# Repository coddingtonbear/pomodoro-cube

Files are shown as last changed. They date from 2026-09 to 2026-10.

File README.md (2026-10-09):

https://github.com/user-attachments/assets/7382e785-1dbb-4c98-959f-1ba87e019f36

# pomodoro-cube

A desk cube that runs a pomodoro timer. Stand it on a face to pick the
interval, lay it face up to pause, lay it face down to switch it off. There are
no buttons — the only control is which way up it is.

The four timer faces

Forked from [fly-robin-fly/coffee_timer](https://github.com/fly-robin-fly/coffee_timer),
which does the same trick for coffee brew times.

The enclosure is on Printables as
[Pomodoro Cube](https://www.printables.com/model/1860676-pomodoro-cube); its
source is in [cad/](cad/README.md).

## Features

- **The faces are the interface** — each face of the cube means something
  different: a 25-minute work timer, a 5-minute break, flow mode's work and its
  break, pause, and off. Nothing to configure and nothing to press: the
  accelerometer reads which face is down, and that is the whole API.
- **Flow mode, for work that doesn't fit a fixed interval** — its work face
  counts *up* for as long as the cube stands on it, banking a fifth of what it
  counts as break time. The break face spends that bank. Fifty minutes of work
  buys ten of break, which is the fixed pair flow mode replaced; an hour and a
  half buys eighteen. Every 25 minutes it counts scores a pomodoro, which is
  what the arc's lap is showing. See [Flow mode](#flow-mode).
- **Home Assistant over BLE** — the cube broadcasts its state as a
  [BTHome v2](https://bthome.io/format/) advertisement, which Home Assistant
  discovers natively: no custom component, no MQTT, no ESPHome. See
  [Bluetooth](#bluetooth).

## How it works

Which way up the cube is sitting is the whole interface. There's an
accelerometer on the board, and the firmware turns what it reports into one of
six states: the four timer faces, face up, or face down.

Standing the cube on a timer face starts that face's timer — or, if you'd
paused one on that same face, picks it back up where you left off. The
countdown faces show an arc that drains as the time runs out, and its colour
says what comes next: a work timer shades from red through amber to green,
heading for the break, and a break shades from green to red, heading back to
work:

The arc draining over a five-minute timer

When a countdown reaches zero, the vibration motor buzzes and the whole face
flashes — green when it's time for a break, red when it's time to get back to
work — until you turn the cube to another face; if you don't, it gives up
and goes to sleep after thirty seconds:

A finished timer flashing

Work timers count towards a running pomodoro total (the one Home Assistant
sees), and breaks don't.

Laying the cube face up pauses whatever's running, and leaves the frozen
countdown on screen in muted colours:

Paused, and the low battery warning

The cube spends most of its life in deep sleep, and any movement wakes it back
up. The paused timer, the pomodoro count and the flow bank are all kept in
memory that survives deep sleep — but not a flat battery.

### Switching off

Face down is off. Every bump wakes a sleeping cube, so "off" has to mean
something a bit stronger than "asleep"; otherwise a cube in a bag would light
up and start a timer whenever it landed on an edge. Once it's face down, the
cube stays dark however much it's jostled, and whatever was running is parked
just as if you'd paused it.

To switch it back on, flip it three times: turn it face up, then over onto
its face and back up again, twice. The screen counts the flips down — a big
**2**, then **1**, "to go" — and answers the third with a buzz and **Let's
go**. Take more than five seconds over any one flip and it goes back to sleep,
still off; the next flip starts the count again from three.

## Flow mode

Sometimes 25 minutes just isn't the right length for a stretch of work. Flow
mode's work face counts _up_ instead of down, for however long you leave the
cube on it, and every five minutes you work banks a minute of break. The flow
break face then counts that bank back down: fifty minutes of work buys you a
ten-minute break, and an hour and a half buys eighteen.

The bank is a running balance rather than a one-time handoff, so several
stretches of work add up, and if you're interrupted partway through a break,
whatever's left stays banked for next time.

Both flow faces are drawn black on white so you can tell at a glance that
you're not on a fixed timer, and the work face shows what your bank would be
if you stopped right now:

Flow mode counting up with its bank, and the break it earned

The arc on the work face fills over 25 minutes and then starts over, counting a
pomodoro each time it comes back around. The first lap shades from red to green
like any work timer; every lap after that runs on from green to cyan, so the
arc snaps back to green each time a pomodoro is scored. The panel lights up for
a couple of seconds either side of that moment so you can see it happen.

## Bluetooth

The cube advertises its state as [BTHome v2](https://bthome.io/format/) —
service data under UUID `0xFCD2` — which Home Assistant discovers with no
custom component, no MQTT and no ESPHome. It is one-way and connectionless, so
it costs almost nothing next to the backlight.

Objects, in the ascending order the spec requires, totalling 30 of the 31 bytes
a legacy advertisement allows:

| Object | ID | Type | Meaning |
| --- | --- | --- | --- |
| Packet ID | `0x00` | uint8 | Increments on change, so receivers can dedupe |
| Voltage | `0x0C` | uint16, ×0.001 V | The smoothed pack voltage, uncorrected |
| Work | `0x0F` | binary | 1 for a work interval, 0 for a break |
| Connectivity | `0x19` | binary | 1 while awake, 0 in the advert sent before sleeping |
| Running | `0x27` | binary | Is the countdown advancing |
| Count | `0x3D` | uint16 | Pomodoros since the last power cycle: completed work timers, plus a flow lap each 25 minutes |
| Duration | `0x42` | uint24, ×0.001 s | Remaining, or elapsed while counting up |
| Duration 2 | `0x42` | uint24, ×0.001 s | What the timer started at, or 0 while counting up |

`Duration 2 == 0` means the timer is counting up, and `Duration` is then the
elapsed time.

Before it goes to sleep, the cube sends one last advertisement with `running`
off, so Home Assistant doesn't go on thinking a timer is running while the cube
is asleep.

### How it reaches the air

The work is split in two, because the halves fail in different ways and only one
of them can be tested without a radio:

- `bthome.cpp` assembles the payload, and is tested against exact bytes. It also
  holds `BTHome::Sequencer`, which decides when there is anything new to say:
  the firmware offers its state on every pass of the loop and the sequencer only
  produces an advertisement when the bytes a receiver would see have changed.
  That is what keeps the packet id meaning *"something changed"* rather than
  *"another second went by"* — and it is why a pack voltage wobbling below a
  millivolt doesn't churn it, since the comparison is on encoded bytes rather
  than the float behind them.
- `ble.cpp` hands the result to NimBLE. Non-connectable, no scan response, no
  GATT server and nothing to connect to: a BTHome device is a beacon. The radio
  goes on the air in two-second bursts at 100 ms, and is quiet in between.
  `BTHome::Scheduler` decides when a burst is due: at once when anything but the
  seconds remaining or the pack voltage has changed, and otherwise every 30
  seconds as a heartbeat, carrying wherever the countdown and the pack have got
  to. Home Assistant's countdown is therefore up to 30 seconds stale, and face
  changes, pauses, finishes and pomodoros arrive at once. The farewell goes out
  at the same 100 ms and stays on the air for the whole of the shutdown sequence — the panel
  being put away, the parting buzz, a second's pause — with the controller
  shut down last, immediately before the CPU stops, and never after less than a
  second on the air. That is a dozen-odd copies of the one advertisement that
  cannot be repeated later, where a fixed 400 ms used to send four, which a
  receiver scanning at a low duty cycle (an ESPHome Bluetooth proxy listens for
  30 ms in every 320 by default) could miss altogether.

The cube appears in Home Assistant under its BLE MAC — one above the WiFi MAC
printed on the board — because the payload already uses 30 of the 31 bytes a
legacy advertisement holds and there is nowhere left to put a name.

> [!NOTE]
> Home Assistant only offers a BTHome device its Bluetooth integration has
> actually *seen*, and the cube is silent while asleep. Stand it on a face before
> adding the integration, or there will be nothing to find.

The simulator prints the payload the firmware last published when you press `a`,
and `SIM_BLE_TRACE=1` prints every one as it goes out:

```
[sim] advertisement 3 (30 bytes): 02 01 06 1A 16 D2 FC 44 00 02 0C 3C 0F 0F 01 19 01 27 01 3D 00 00 42 90 DB 16 42 60 E3 16
[sim] farewell advertisement 4 (30 bytes): 02 01 06 1A 16 D2 FC 44 00 03 0C 3C 0F 0F 01 19 00 27 00 3D 00 00 42 90 DB 16 42 60 E3 16
```

## Hardware

### Parts

- **Board**: [Waveshare ESP32-S3-Touch-LCD-1.28](https://www.waveshare.com/wiki/ESP32-S3-Touch-LCD-1.28)
- **Battery**: a 102535 Li-Po cell ([the one used here](https://www.amazon.com/dp/B0GQB1DCTW))
- **Vibration motor**: [the one used here](https://www.amazon.com/dp/B0FQTHK9LH)
- **Screws**: 4× M2.6 × 6 mm self-tapping: two inside hold the display to the
  center, two outside hold the back on
- **Enclosure**: four printed parts; see [cad/](cad/README.md) or
  [Printables](https://www.printables.com/model/1860676-pomodoro-cube)

### The board

A [Waveshare ESP32-S3-Touch-LCD-1.28](https://www.waveshare.com/wiki/ESP32-S3-Touch-LCD-1.28),
which carries everything except the vibration motor: the 240×240 round GC9A01 over SPI,
a QMI8658 accelerometer over I²C, a LiPo connector with an ETA6096 charger and
the 200k/100k sense divider, and USB-C for flashing. Every pin in
`ArduinoIDE_V2/main/consts.h` matches that board — including the three that
distinguish it from the otherwise similar non-touch `ESP32-S3-LCD-1.28`
(backlight on GPIO2, LCD reset on GPIO14, IMU INT1 on GPIO4).

The one added component is a **vibration motor on GPIO15**, driven high to run
it. That is one of the six GPIOs the board brings out on its SH1.0 connector
(15, 16, 17, 18, 21 and 33), and the pin is held low through deep sleep. A GPIO
cannot supply a motor directly, so this wants a module with its own driver
transistor. There is no sounder: everything the cube has to say, it says by
buzzing.

| When | Pattern |
| --- | --- |
| Waking onto a timer face | Two short pulses |
| Set on a different face, resting faces included | One pulse |
| A timer running out | 400 ms on, 600 ms off, until the cube is turned to another face or sleeps |

A wake that finds the cube still resting goes back to sleep without a buzz,
because a buzz is movement and movement is what wakes it. For the same reason
the motor is stopped before the wake-on-motion detector is armed, taps are
ignored while it runs, and the alarm's silences are longer than the face
debounce, so the accelerometer always gets a quiet stretch in which to notice
the cube being turned. The patterns are in `consts.h`.

The board also has a **CST816S capacitive touch controller**, on the same I²C
bus as the accelerometer, which this firmware does not use at all. It's the
obvious place to start if the cube ever needs configuring on-device rather than
by reflashing.

## Building

Open `ArduinoIDE_V2/main` in the Arduino IDE. Dependencies, all from the
Library Manager:

- TFT_eSPI 2.5.43 (Bodmer)
- lvgl 8.3.11
- SensorLib 0.4.1 (Lewis He) — the library that provides `SensorQMI8658.hpp`.
  Searching the Library Manager for the header's name finds other people's
  QMI8658 libraries instead, none of which are this one
- NimBLE-Arduino 1.4.3 (h2zero) — **not** 2.x, which needs an ESP32 core of 3.x
  and up; this project is on 2.0.14. NimBLE rather than the core's bundled
  `BLEDevice.h` because that one is Bluedroid, which costs tens of kilobytes of
  RAM the cube would rather spend on LVGL

Two of them keep their configuration outside the sketch, and both have to be
linked into place before anything will work:

```bash
ln -s "$PWD/ArduinoIDE_V2/lv_conf.h"    ~/Arduino/libraries/lv_conf.h
ln -s "$PWD/ArduinoIDE_V2/User_Setup.h" ~/Arduino/libraries/TFT_eSPI/User_Setup.h
```

`lv_conf.h` sets only the five options that differ from LVGL's defaults, and
`sim/CMakeLists.txt` sets the same five, so the simulator and the board render
from identical settings. LVGL looks for it one directory *above* itself, which
is why it cannot live in the sketch folder.

`User_Setup.h` is the panel: GC9A01, 240×240, and the SPI pins. TFT_eSPI does
support a `tft_setup.h` in the sketch folder and this project used to rely on
it, but **that mechanism cannot work under the Arduino build**: TFT_eSPI.h
looks for `<tft_setup.h>` on the include path, and the sketch folder is not on
the path when the build compiles the library itself. The sketch's own files
find it and the library's do not, so the library compiles against its default
— an ILI9341 on entirely different pins — and the panel stays black with
nothing anywhere to say why. Overriding `User_Setup.h` configures every
translation unit alike. `display.cpp` now refuses to compile if `GC9A01_DRIVER`
is undefined, so a missing symlink is a build error rather than a dead screen.

Board settings, matching the ESP32-S3-WROOM-1 the Waveshare board carries:
**ESP32S3 Dev Module**, flash size **16MB**, PSRAM **disabled** (this module
has none). USB CDC on boot stays **disabled** — the USB-C port is a CH343
UART bridge rather than the S3's native USB, so `Serial` is UART0 either way
and the port appears as `/dev/ttyACM0`. The default 4MB partition scheme is
kept despite the 16MB flash: the sketch is about 880 kB against that scheme's 1.3 MB
app slot, and nothing here uses the filesystem.

The IDE isn't needed to flash it, though — `tools/flash.sh` compiles and
uploads in one go with the `arduino-cli` the IDE ships with, passing those board
settings itself. It also builds at `-O2` rather than the core's `-Os`, which
draws the face about 14% faster; the IDE has no setting for that, so an IDE
build works the same and just draws a little slower:

```bash
tools/flash.sh              # compile, upload, reset
tools/flash.sh --build-only # just check it compiles
tools/flash.sh --monitor    # ...and then tail UART0 at 115200
```

It checks the two symlinks above before compiling, loads `cdc_acm` if
`/dev/ttyACM0` is missing (the module is blacklisted on some machines, so the
port doesn't appear on its own), and resets the board a second time after
uploading — straight out of an upload the QMI8658 has come up silent, with
every read returning zero, and a second reset clears it.

`ArduinoIDE_V2/main/src/` began life as SquareLine Studio output and is now
maintained by hand. **Re-exporting from `SquareLine/coffee_timer.spj` would
overwrite it**, countdown font included.

## Developing without the hardware

```bash
./sim/run.sh
```

This compiles the real firmware for a Linux desktop and draws LVGL into an SDL
window instead of a GC9A01 over SPI. It isn't a reimplementation: `main.ino`,
`display.cpp`, `util.cpp`, `indicators.cpp`, `rtc_state.cpp`, `tilt.cpp`,
`bthome.cpp`, `battery.cpp`, `haptic.cpp` and `haptic_pattern.cpp` all compile
exactly as they ship, against fake `Arduino.h`, `TFT_eSPI`, `Wire` and
`driver/rtc_io` headers. Only `qmi.cpp` and `ble.cpp` are replaced, because they
need the vendor IMU driver and NimBLE.

RTC memory is modelled rather than faked — the block survives a simulated deep
sleep, and a cold boot fills it with junk rather than zeroes, so the magic-word
guard is genuinely exercised.

See [sim/README.md](sim/README.md) for the controls, the scripted-screenshot
environment variables, and what the simulator can't tell you.

Host tests cover the parts that are pure logic — the face-to-timer mapping, the
flow bank's arithmetic, the arc's fill and colour ramp, the lap indicator
and what scores off it, the switch from 25:00 to 1h25 past an hour, the low-battery threshold,
the angle the face is drawn at, the RTC guard, the vibration patterns, the
order the sleep path shuts things down in, and the BTHome encoder's exact output
bytes:

```bash
cmake --build sim/build && ctest --test-dir sim/build --output-on-failure
```

## Changing the countdown font

```bash
tools/convert-font.sh fonts/Oswald-SemiBold.ttf 62
```

The font slot is named for its role rather than the typeface, so nothing else
needs editing. The script subsets to the digits and colon, renders at 4 bpp for
antialiasing, and equalises the digit widths so the countdown doesn't shift
sideways as it ticks — most faces draw a much narrower `1` than `0`, and on a
centred label that slides the whole time every second.

The current face is [Oswald](https://github.com/google/fonts/tree/main/ofl/oswald)
SemiBold at 62px, chosen because it's condensed: on a 240px round panel with an
arc eating the edges, height is the scarce resource. See
[fonts/README.md](fonts/README.md) for why the weight is pinned to a static
instance.

## Layout

```
ArduinoIDE_V2/lv_conf.h   LVGL settings, linked into ~/Arduino/libraries
ArduinoIDE_V2/User_Setup.h TFT_eSPI panel settings, linked into the library
ArduinoIDE_V2/main/       the firmware, built with the Arduino IDE
ArduinoIDE_V2/main/src/   the LVGL UI, originally SquareLine Studio output
SquareLine/               the SquareLine Studio project the UI came from
cad/                      the enclosure, exported from Fusion 360; see cad/README.md
fonts/                    source faces for the countdown label
sim/                      desktop simulator and host tests
tools/                    flashing the board, and font conversion
```

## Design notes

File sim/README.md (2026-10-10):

# Desktop simulator

Runs the cube's firmware on a Linux desktop, with LVGL drawing into an SDL
window instead of into the GC9A01 over SPI. The point is to be able to work on
the UI and the timer behaviour without the hardware.

The firmware is **not** forked for this. `main.ino`, `display.cpp`, `util.cpp`,
`battery.cpp` and `haptic.cpp` are compiled exactly as they ship, against the
shims in `shim/`. The one exception is `qmi.cpp`, which needs the vendor
QMI8658 driver; `src/sim_qmi.cpp` stands in for it and synthesises an
accelerometer reading for whichever face the sim says the cube is resting on.

## Running

```bash
./run.sh
```

First run fetches LVGL v8.3.11 (matching what SquareLine Studio generated
against) and configures CMake; later runs just rebuild. Needs `cmake`, a C++17
compiler and `libsdl2-dev`:

```bash
sudo apt install cmake build-essential libsdl2-dev
```

## Controls

| Key | Effect |
| --- | --- |
| `1` `2` `3` `4` | Rest the cube on a face — 0°, 90°, 180°, 270° |
| | `3` is flow's work face, which counts up, and `4` spends the break it banks |
| `z` `x` | Lean it 5° anticlockwise / clockwise off that face, up to 40° |
| `0` or `s` | Lay it face down |
| `u` | Lay it face up. On a switched-off cube, `u` `0` `u` `0` `u` is the three flips that switch it on |
| `b` | Cycle the low-battery warning: forced on, forced off, voltage-driven |
| `[` `]` | Lower / raise the simulated pack voltage |
| `t` | Tap the cube, which brightens the panel for ten seconds |
| `d` | Double-tap it |
| `v` | Toggle between the viewer's view and the raw panel |
| `m` | Toggle the round-panel mask |
| `a` | Print the BLE advertisement the firmware last published |
| `r` | Reboot, as a wake-from-deep-sleep would |
| `q` or `Esc` | Quit |

`b` exists because nudging the voltage is a slow way to see the warning: the
firmware averages ten readings taken five seconds apart, so a change takes most
of a minute to land. The forced states still go through the firmware's own
threshold, just with the voltage model skipped. `[` or `]` hands control back.

By default the window shows the panel as someone looking at the cube sees it:
turned to the angle the cube is held at, which is the face it is on plus any
lean. A face that has caught up with the cube is therefore upright, and one
that has not is as crooked as it would be in the hand — which is the only way
to see a turn being eased. `v` switches to the physical panel, where the
content appears rotated — useful when checking what `tft.setRotation()` is
actually doing.

The simulated cube changes face in no time at all, which no hand does, so a
turn here is the worst case the easing has to cope with rather than what one
looks like.

Face down switches off and blanks the panel; face up pauses, leaving the frozen
countdown lit. Either way any key re-executes the process, reproducing the cold
boot the IMU interrupt causes on hardware. A face key wakes onto that face and
any other key onto 90°. To switch a face-down cube back on, wake it with `u`
and press `k` or `d` within five seconds.

## Scripted screenshots

Environment variables let a script capture the panel without a display:

```bash
SDL_VIDEODRIVER=dummy SIM_ORIENTATION=180 \
  SIM_SCREENSHOT=/tmp/face.bmp SIM_SCREENSHOT_MS=1500 ./build/sim
```

| Variable | Effect |
| --- | --- |
| `SIM_ORIENTATION` | Boot on a face: `0`, `90`, `180`, `270`, `up` or `down` |
| `SIM_BATTERY` | Starting pack voltage in volts, e.g. `3.35` |
| `SIM_SCREENSHOT` | Where to write the frame |
| `SIM_SCREENSHOT_MS` | When to grab it, in ms since boot |
| `SIM_KEYS` | Keys to press, e.g. `b`, `mv`, or `u@12000` for 12s in |
| `SIM_BLE_TRACE` | Print every BLE advertisement as it goes out |
| `SIM_TIME_SCALE` | Run the firmware's clock this many times faster than real time, e.g. `600` |

`SIM_KEYS` entries are comma-separated, and `key@ms` presses one part-way
through a run — which is how pausing gets exercised, since it needs a face
change while a countdown is already going.

`SIM_BLE_TRACE` with `SIM_KEYS` is how the advertising sequence gets checked
without a keyboard — including the farewell, which only goes out on the way into
deep sleep:

```bash
SDL_VIDEODRIVER=dummy SIM_BLE_TRACE=1 SIM_ORIENTATION=0 SIM_KEYS=u@6000 ./build/sim
```

`SIM_SCREENSHOT_MS` also takes a comma-separated list, which captures a
countdown at several points in one run; each file then gets its elapsed time
appended to the name. The sim exits after the last capture.

```bash
SDL_VIDEODRIVER=dummy SIM_ORIENTATION=90 SIM_SCREENSHOT=/tmp/arc.bmp \
  SIM_SCREENSHOT_MS=1000,76000,151000,226000 ./build/sim
```

`SIM_TIME_SCALE` speeds up `millis()`, `delay()`, and with them the times in
`SIM_KEYS` and `SIM_SCREENSHOT_MS`, which are all in simulated milliseconds.
A flow stint past its first hour is a minute away at `100`:

```bash
SDL_VIDEODRIVER=dummy SIM_TIME_SCALE=100 SIM_ORIENTATION=180 \
  SIM_KEYS=t@5995000 SIM_SCREENSHOT=/tmp/hour.bmp SIM_SCREENSHOT_MS=6000000 ./build/sim
```

The timer on screen falls behind the clock, though. The firmware advances it
by at most one second per pass of `loop()`, and a pass still takes as long on
the wall clock as its drawing does — a few milliseconds, which at `100` is
most of a simulated second. The run above shows about 1:18, not 1:40, and at
`600` a pass is several seconds and an hour's run shows about fifteen minutes.
Aim a screenshot by what is on screen rather than by the arithmetic, and keep a
tap no more than a few simulated seconds before the capture it is meant to
brighten.

## Tests

`tests/` holds host tests for the firmware's pure logic — the face-to-timer
mapping and the flow bank's arithmetic in `util.cpp`, the
accelerometer vectors the faces correspond to, and the arc fill, arc colour,
flow lap indicator, switch from 25:00 to 1h25 and low-battery threshold in
`indicators.cpp`. They build as part of the same project:

```bash
cmake --build build && ctest --test-dir build --output-on-failure
```

## What is and isn't simulated

Faithful: the LVGL render path and the SquareLine UI, panel rotation, the
countdown and its debounce, the arc and battery indicator, the deep-sleep
transitions, and RTC memory — the block survives a simulated deep sleep and is
filled with junk on a cold boot, exactly as the real thing would be, so the
magic-word guard is genuinely exercised rather than getting away with a benign
block of zeroes. A paused panel stays lit because the sim decides from the
panel's own state (backlight on, no Sleep In command) rather than from knowing
the firmware is asleep.

One gap around pausing: the device holds `TFT_BL_PIN` through deep sleep, so the
frame stays lit across the wake until `Display::setup()` releases the hold. The
sim's wake is a fresh process, so its panel goes dark for the moment the boot
takes. Nothing depends on it, but the real cube will look slightly smoother.

There is no radio: `a` prints the BTHome payload `bthome.cpp` builds rather than
transmitting it, which is enough to read a payload back against the spec or paste
it into a decoder.

Stubbed: the vibration motor is a flag that follows its pin and shows up in the
window title as `BUZZ`, so the pattern timing is visible. It does not shake the
simulated accelerometer, so how the motor disturbs the IMU is a question for the
board. I2C,
RTC GPIO holds and the CPU frequency change are no-ops. Timing comes from the
host clock, so this says nothing about how the real ESP32 performs at 80 MHz.

## Layout

```
shim/     Arduino.h, TFT_eSPI, Wire, driver/rtc_io -- the hardware APIs faked
src/      the simulated panel, input state, IMU stand-in and SDL entry point
tests/    host tests for the firmware's pure logic, plus link stubs
```

`shim/` is deliberately minimal: only the calls this firmware actually makes are
provided, so reaching for a new hardware API shows up as a compile error rather
than silently doing nothing.

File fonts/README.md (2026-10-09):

# Fonts

Source faces for the countdown label and the switch-on prompt, kept here so
the conversion is reproducible. `tools/convert-font.sh` reads from here and
writes `ArduinoIDE_V2/main/src/ui_font_Countdown_54.c` (or wherever `OUT`
says).

## Oswald-SemiBold.ttf

The countdown face. Oswald is a variable font upstream; this is the wght=600
instance, pinned with:

```
fonttools varLib.instancer Oswald[wght].ttf wght=600 -o Oswald-SemiBold.ttf
```

The instance matters — `lv_font_conv` takes a variable font's default instance,
which for Oswald is Regular, and Regular is too light for the panel.

Regenerate the countdown font with:

```
RANGE=0x30-0x3A,0x68 tools/convert-font.sh fonts/Oswald-SemiBold.ttf 62
```

The range adds `h` to the digits and colon, for the hours past an hour (1h25).

62px rather than the script's default 54: Oswald is condensed, so it can run
taller before the digits reach the arc.

The switch-on prompt's count is the same face, much larger, and only the two
digits it ever shows:

```
OUT=$PWD/ArduinoIDE_V2/main/src/ui_font_FlipCount.c RANGE=0x31-0x32 TABULAR=0 \
  tools/convert-font.sh fonts/Oswald-SemiBold.ttf 150
```

Licensed under the SIL Open Font License 1.1, in `OFL.txt`.
Upstream: https://github.com/google/fonts/tree/main/ofl/oswald

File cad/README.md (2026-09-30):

# Enclosure

A 44.9 mm cube, designed in Fusion 360. The design is the Fusion document
**Pomodoro Box**; the files here are exports of it, and are replaced wholesale
whenever it changes rather than edited.

It's published on Printables as
[Pomodoro Cube](https://www.printables.com/model/1860676-pomodoro-cube).

| file | what it is |
|---|---|
| [`pomodoro-cube.f3d`](pomodoro-cube.f3d) | the Fusion 360 design itself, for opening and remixing |
| [`pomodoro-cube.step`](pomodoro-cube.step) | the assembly: one component per part, in their assembled positions, without the board |
| [`pomodoro-cube.3mf`](pomodoro-cube.3mf) | all four parts laid out on one plate, ready to slice |
| [`step/`](step/) | one STEP per part, oriented for printing like the STLs |
| [`stl/`](stl/) | one STL per printed part, already oriented for printing |

To print, open the 3MF, or the per-part STEPs or STLs. The assembly STEP is for
CAD; a slicer would load its parts nested inside each other.

## The parts

| part | size (mm) | print | files |
|---|---|---|---|
| center | 44.9 × 44.9 × 38.9 | upright, as designed | [STL](stl/pomodoro-cube-center.stl), [STEP](step/pomodoro-cube-center.step) |
| face | 44.9 × 44.9 × 11.4 | outer face down | [STL](stl/pomodoro-cube-face.stl), [STEP](step/pomodoro-cube-face.step) |
| back | 44.9 × 44.9 × 3.0 | outer face down | [STL](stl/pomodoro-cube-back.stl), [STEP](step/pomodoro-cube-back.step) |
| barrier | 38.5 × 38.5 × 1.0 | flat | [STL](stl/pomodoro-cube-barrier.stl), [STEP](step/pomodoro-cube-barrier.step) |

**Center** is the shell, with the display pocket, the internal ledges and the
openings in its side walls. **Face** is the display's front and
plugs into the top of it; **back** closes the bottom. **Barrier** is a thin
plate that sits inside the shell about 10 mm behind the display.

Besides the board, it holds a 102535 Li-Po battery and a vibration motor, and
four M2.6 × 6 mm self-tapping screws hold it together: two inside fix the
display to center, and two outside fix back to center. See
[Parts](../README.md#parts) for links.

Each STL was checked watertight on export, and each part lies in whichever
axis-aligned orientation leaves the least overhang steeper than 45°. Face still
has some, from the display bevel and the edge rounds on the bed.

## Updating

Fusion runs on another machine, so exports are made there and copied in. When
the design changes, replace every file here, keeping the names so links to them
survive:

- **Fusion archive**: the design as-is.
- **STL**: every body, in its print orientation.
- **STEP**: the design keeps all four parts as bodies of one component, so
  exporting the root gives a single part that slicers load as one lump. Instead,
  copy the bodies into a scratch design with one component each: one set in
  place, exported together as the assembly, and one set rotated to print
  orientation (face and back turn 180° about X), each exported alone.
- **3MF**: all four parts, in print orientation, as separate objects on one
  plate. The current one was built from the STLs, in a 2 × 2 grid with 10 mm
  gaps centred at (100, 100) so it fits a 180 mm bed.

## History

Until September 2026 the enclosure was a parametric build123d model here: a
55 mm cube in a band, two plates and two clamp bars, with every dimension
derived from the board's published STEP. It was taken into Fusion and then
redesigned there over many iterations, and was removed once it no longer
described the part that is printed. It is in the git history before this
directory was replaced.

The shell descends from Robin's
[Timer cube](https://www.printables.com/model/1774785-timer-cube), the
enclosure for [fly-robin-fly/coffee_timer](https://github.com/fly-robin-fly/coffee_timer),
which the firmware here is forked from.

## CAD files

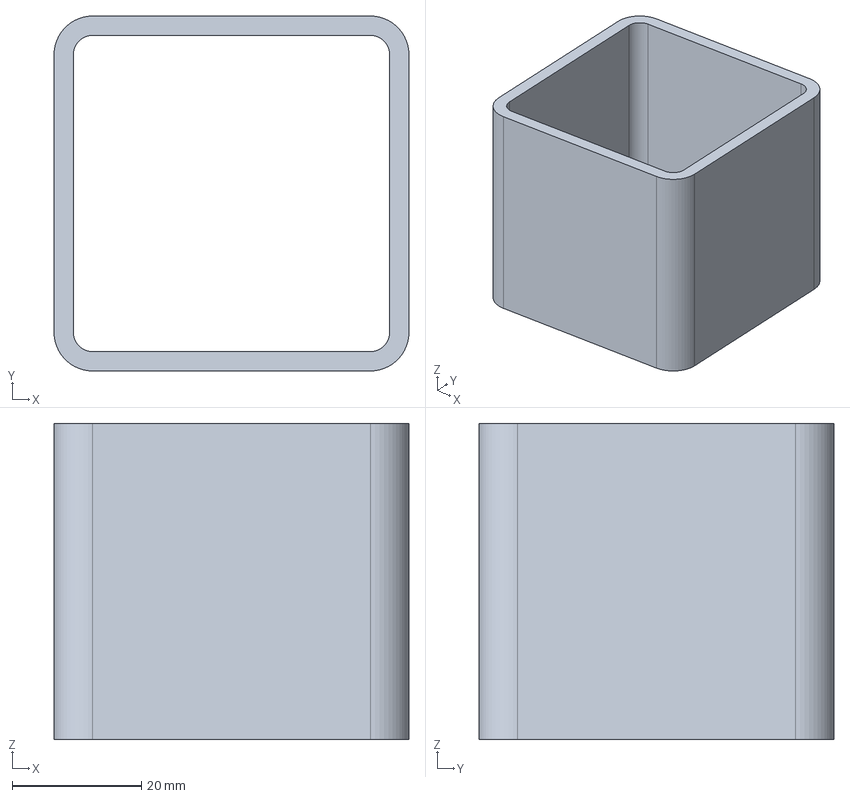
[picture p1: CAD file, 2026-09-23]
cad/build/band-plates-as-faces.step
55.0 x 55.0 x 49.0 mm

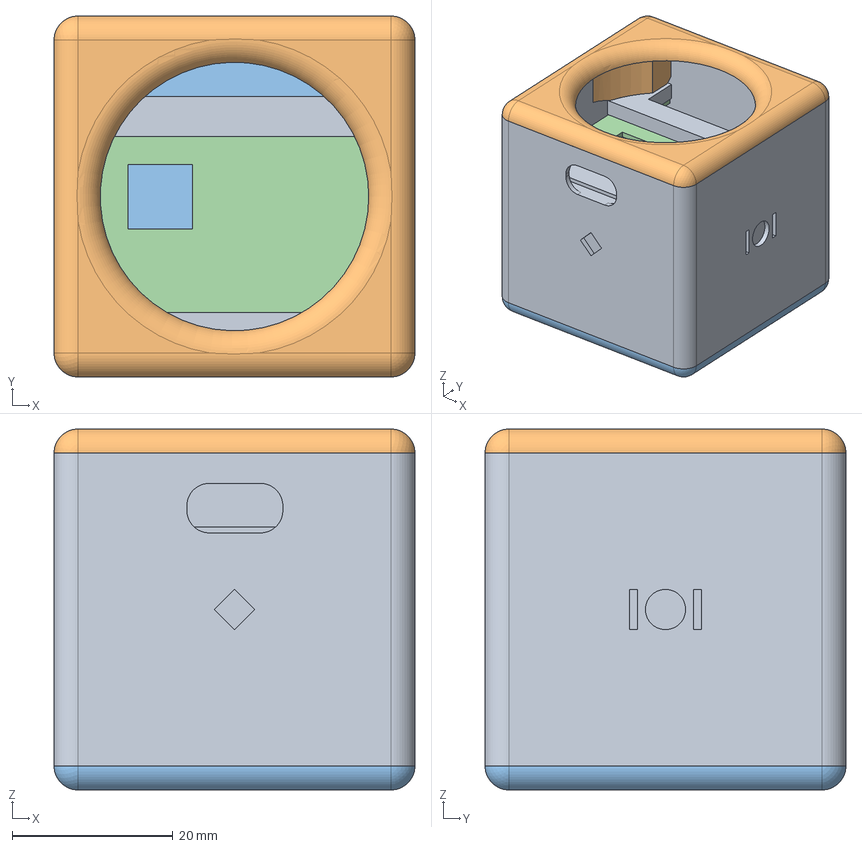
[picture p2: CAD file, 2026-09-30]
cad/pomodoro-cube.step
44.9 x 44.9 x 44.9 mm
Center
Back
Barrier

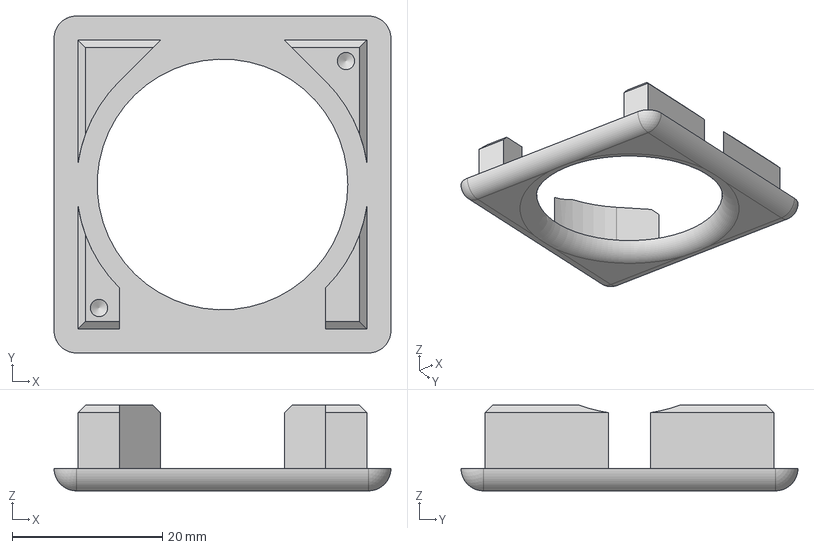
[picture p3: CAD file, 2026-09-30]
cad/step/pomodoro-cube-face.step
44.9 x 44.9 x 11.4 mm

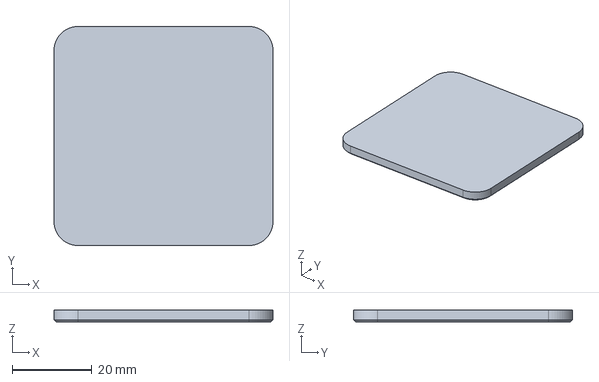
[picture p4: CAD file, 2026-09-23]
cad/build/back-plate-plates-as-faces.step
55.0 x 55.0 x 3.00 mm

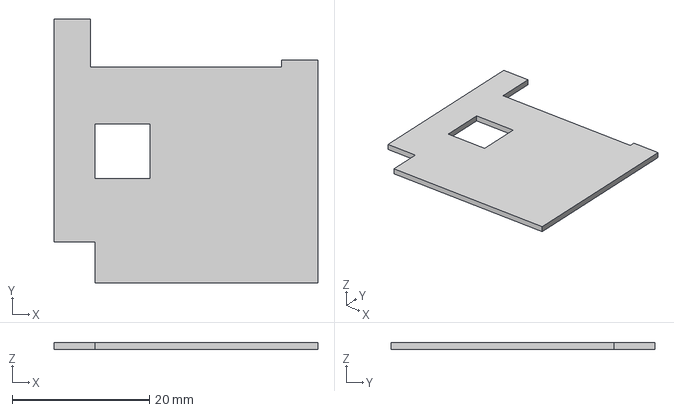
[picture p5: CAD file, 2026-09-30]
cad/step/pomodoro-cube-barrier.step
38.5 x 38.5 x 1.00 mm

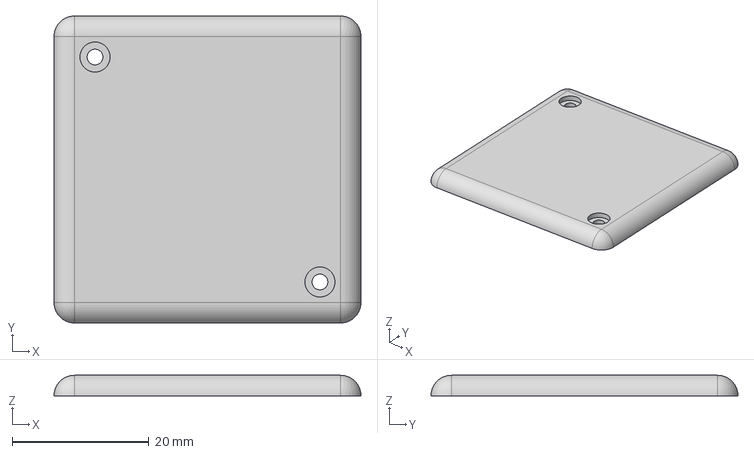
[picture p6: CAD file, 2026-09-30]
cad/step/pomodoro-cube-back.step
44.9 x 44.9 x 3.00 mm

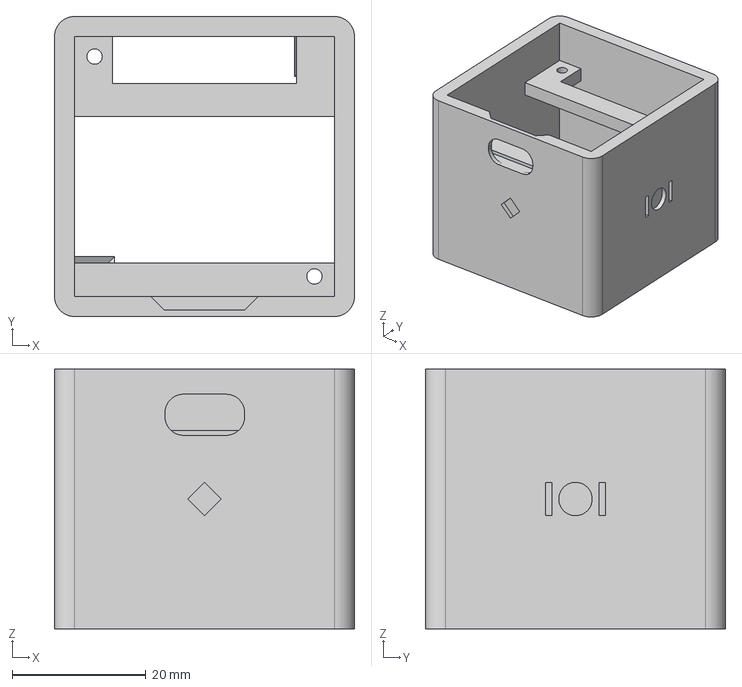
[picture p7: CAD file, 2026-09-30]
cad/step/pomodoro-cube-center.step
44.9 x 44.9 x 38.9 mm

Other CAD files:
cad/pomodoro-cube.3mf
cad/pomodoro-cube.f3d
cad/stl/pomodoro-cube-back.stl
cad/stl/pomodoro-cube-barrier.stl
cad/stl/pomodoro-cube-center.stl
cad/stl/pomodoro-cube-face.stl

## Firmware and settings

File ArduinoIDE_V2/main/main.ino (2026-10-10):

#include <Arduino.h>
#include "consts.h"
#include "battery.h"
#include "display.h"
#include "util.h"
#include "display.h"
#include "qmi.h"
#include <lvgl.h>
#include "haptic.h"
#include "rtc_state.h"
#include "ble.h"
#include "tilt.h"
#include "nap.h"


// Counting down, this is the time left. Counting up, it is the time elapsed.
int remSeconds = 0;
// The interval being counted down, and 0 while counting up: nothing was chosen.
int selSeconds = 0;
TimerKind timerKind = TimerKind::Work;
TimerMode timerMode = TimerMode::Countdown;
// True when the countdown on screen is the flow bank draining, so each tick has
// to write the new balance back. The fixed faces leave the bank alone.
bool spendingFlowBank = false;
// One of flow's faces, either of them: the panel inverts for both.
bool onFlowFace = false;
unsigned long lastTick = 0;  // last count tick timestamp
// When the timer on screen ran out, which is what the sleep that ends an
// unanswered alarm is timed from.
unsigned long startedAlarm = 0;
// The timer face the cube was last stood on, so a pause knows what it paused.
Orientation lastTimerFace = Orientation::UNDEFINED;
// When the cube was last set on a different face. Only the backlight reads it:
// a face change is a decision worth lighting the panel for.
unsigned long lastFaceChange = 0;
// When the cube was last tapped, or 0 for not since this boot. Only the
// backlight reads this one too.
unsigned long lastTap = 0;
// When a reading last showed the cube being moved, which keeps the loop fast
// for a moment after it stops.
unsigned long lastMoved = 0;
// Lying face up with a timer parked, and awake: nothing counts, the panel
// shows the parked figures, and the loop goes on watching the faces so that
// standing the cube back up is a face change like any other rather than a
// wake. `pausedAt` is what the sleep that ends a forgotten pause is timed from.
bool paused = false;
unsigned long pausedAt = 0;

// The angle the face is drawn at, followed from the accelerometer on every
// pass. Nothing to do with which face the cube is on, which is debounced and
// chooses the timer; this only turns the picture.
Tilt::Tracker tilt;

// Feed the tracker whatever the accelerometer had to say, including nothing.
// True when the angle to draw has moved.
bool senseTilt(bool haveReading, float ax, float ay, float az) {
  return tilt.update(haveReading && Util::isGravityOnly(ax, ay, az), ax, ay, millis());
}

// How long since the last tap, or past any window when there has not been one.
// millis() - 0 is millis(), which reads as a tap a moment ago for the first ten
// seconds of every boot.
unsigned long sinceTap() {
  return lastTap == 0 ? ~0UL : millis() - lastTap;
}


// A flow stint has ended: a fifth of it is credited to the break bank, on top of
// whatever was already there. Any stint that counted a second at all credits
// something -- a cube turned through the flow face on its way elsewhere never
// reaches a second, so there is nothing to screen out.
//
// Nothing is counted here. A stint scores by the lap while it runs, not by the
// stint when it stops, so its last partial lap is worth no more than abandoning
// a 25-minute timer at 24:00 is.
void bankFlowStint(int elapsed) {
  RtcState::addFlowBank(RtcState::data(), Util::flowBreakCredit(elapsed));
}

bool countingUp() {
  return timerMode == TimerMode::CountUp;
}

// What the panel is drawn from. The bank shown on a running stint includes what
// that stint has earned so far, because what you want to know while looking at
// it is what turning the cube over would give you.
Display::TimerView timerView() {
  const int banked = RtcState::flowBank(RtcState::data());
  return {remSeconds, selSeconds, countingUp(), onFlowFace, timerKind == TimerKind::Work,
          countingUp() ? Util::flowBankPreview(banked, remSeconds) : banked};
}

// What goes out over BLE. The packet id is left at zero: BLE::publish() hands
// this to a BTHome::Sequencer, which numbers it and drops it if nothing has
// changed, so this is free to be called on every pass.
BTHome::State bthomeState() {
  BTHome::State state;
  state.packetId = 0;
  state.batteryVolts = Util::batteryVolts();
  state.awake = true;
  // A stint counting up is running from its first second, before remSeconds has
  // anything in it.
  state.running = !paused && (countingUp() || remSeconds > 0);
  state.work = timerKind == TimerKind::Work;
  state.pomodoroCount = RtcState::data().pomodoroCount;
  state.remainingSeconds = remSeconds;
  state.selectedSeconds = selSeconds;
  return state;
}


// Everything standing the cube on a timer face asks for: closing off whatever
// the face being left was counting, picking up a pause that belongs to the new
// one, and repainting to match. Called from loop() when the debounce settles,
// and from setup() for the face a wake settles onto -- that one has already
// been through the debouncer, so nothing in loop() would announce it.
void applyFace(Orientation ori) {
  // Turning off the flow face ends the stint it was counting. Not out of a
  // pause, where the stint is the parked one and is banked as that below.
  if (!paused && countingUp() && ori != lastTimerFace) bankFlowStint(remSeconds);
  paused = false;

  // So does standing the cube on a face that abandons a parked one. The
  // pause itself is consumed by takePause() below either way; this is only
  // about banking what it was worth.
  {
    const RtcState::Data &stored = RtcState::data();
    if (RtcState::hasPause(stored) && stored.pausedCountingUp &&
        stored.pausedFace != ori) {
      bankFlowStint((int)stored.pausedRemaining);
    }
  }

  lastTimerFace = ori;

  // Read rather than spend: the bank is a balance, and only the break face
  // draining it writes it down. Every other face leaves it where it is, so
  // a spell on the 25-minute face doesn't cost you the break you earned.
  const Util::TimerSpec spec = Util::getTimerSpec(ori, RtcState::flowBank(RtcState::data()));
  spendingFlowBank = spec.spendsBank;
  onFlowFace = spec.flow;

  bool resumesCountingUp = false;
  if (RtcState::takePause(RtcState::data(), ori, remSeconds, selSeconds,
                          resumesCountingUp)) {
    timerMode = resumesCountingUp ? TimerMode::CountUp : TimerMode::Countdown;
    timerKind = spec.kind;
  } else {
    timerKind = spec.kind;
    timerMode = spec.mode;
    remSeconds = spec.mode == TimerMode::CountUp ? 0 : spec.seconds;
    selSeconds = spec.mode == TimerMode::CountUp ? 0 : spec.seconds;
  }
  // A break face turned to with an empty bank has no time to count, so it
  // is finished before it starts. Dating the alarm from here rather than
  // leaving the last finish's timestamp in place is what gives it the usual
  // thirty seconds before sleeping, instead of a stale one that could sleep
  // the cube on the spot.
  if (!countingUp() && remSeconds == 0) startedAlarm = millis();

  // At the angle the cube is actually held, which by now the tracker has been
  // following for at least the length of the debounce. The face's own angle is
  // only the fallback for a tracker that has somehow heard nothing.
  if (!tilt.hasAngle()) tilt.seed(Tilt::faceAngle(ori));
  Display::setAngle(tilt.angle());
  Display::updateTimer(timerView());
  lastTick = millis();
}

// Poll the accelerometer until one reading has held still long enough to be
// believed, or until the cube has plainly been in a hand for too long to wait
// out. UNDEFINED means it never settled, which is not a resting face and so
// boots the cube -- the right way round to be wrong.
Orientation settleOrientation() {
  const unsigned long deadline = millis() + WAKE_SETTLE_TIMEOUT_MS;
  while (millis() < deadline) {
    float ax, ay, az;
    const bool haveReading = QMI::getAccelerometer(ax, ay, az);
    // Followed from here, with no panel up yet to draw on, so that the first
    // frame is drawn at the angle the cube is held at rather than swinging
    // round to it.
    senseTilt(haveReading, ax, ay, az);
    if (haveReading && Util::updateOriDebounce(ax, ay, az, millis())) {
      return Util::getDebouncedOriState();
    }
    delay(20);
  }
  return Orientation::UNDEFINED;
}

// The frame a parked cube shows: the figures as they stood when it was set
// down, drawn from the stored pause rather than from the live timer, which on
// this path has not been set up and holds nothing.
Display::TimerView pausedView(const RtcState::Data &stored) {
  const int banked = RtcState::flowBank(stored);
  // The face it was paused from is what says whether this is one of flow's,
  // which the break face is as much as the work face -- countingUp alone would
  // draw a paused flow break in the fixed faces' colours.
  const Util::TimerSpec spec = Util::getTimerSpec(stored.pausedFace, banked);
  const bool up = stored.pausedCountingUp;
  return {(int)stored.pausedRemaining, (int)stored.pausedSelected, up, spec.flow,
          spec.kind == TimerKind::Work, up ? Util::flowBankPreview(banked, (int)stored.pausedRemaining) : banked};
}

// Hold the parked timer on the panel with the cube awake. The pause itself is
// already in RTC memory, which is where standing the cube back up will take it
// from; the live timer is set to match so that what is advertised, and what is
// parked again if the cube is turned face down from here, are the same figures.
void holdPause() {
  const RtcState::Data &stored = RtcState::data();
  const Util::TimerSpec spec =
      Util::getTimerSpec(stored.pausedFace, RtcState::flowBank(stored));
  lastTimerFace = stored.pausedFace;
  remSeconds = (int)stored.pausedRemaining;
  selSeconds = (int)stored.pausedSelected;
  timerMode = stored.pausedCountingUp ? TimerMode::CountUp : TimerMode::Countdown;
  timerKind = spec.kind;
  spendingFlowBank = spec.spendsBank;
  onFlowFace = spec.flow;

  paused = true;
  pausedAt = millis();

  // Square on the face the timer was running on, which is how a wake that has
  // to redraw this frame will draw it. A cube laid down part-way through a
  // turn would otherwise be parked at whatever angle the turn had reached.
  Display::rotateScreen(stored.pausedFace);
  Display::updateTimer(pausedView(stored));
  Display::showPaused();
}

// Follow the faces for up to `forMs`, and return the first face other than
// `current` the cube settles on, or `current` if it settles on nothing else.
Orientation watchFaces(unsigned long forMs, Orientation current) {
  const unsigned long started = millis();
  while (millis() - started < forMs) {
    feedLoopWDT();
    float ax, ay, az;
    if (QMI::getAccelerometer(ax, ay, az) && Util::updateOriDebounce(ax, ay, az, millis())) {
      const Orientation face = Util::getDebouncedOriState();
      if (face != current) return face;
    }
    delay(20);
  }
  return current;
}

// A switched-off cube has been woken: listen for the gesture that switches it
// back on. Dark and silent until the first flip -- no panel, no radio, no buzz
// -- because most wakes of a switched-off cube are a bag being carried, and the
// only thing worth spending on one of those is getting back to sleep.
bool heardSwitchOn() {
  Util::SwitchOnListener listener(millis());
  for (;;) {
    feedLoopWDT();
    float ax, ay, az;
    const bool haveReading = QMI::getAccelerometer(ax, ay, az);
    const Util::SwitchOnVerdict verdict = listener.update(haveReading, ax, ay, az, millis());
    if (verdict != Util::SwitchOnVerdict::Listening) {
      Serial.printf("[trace] SWITCH_ON verdict=%d flipsToGo=%d\n", (int)verdict,
                    listener.flipsToGo());
      return verdict == Util::SwitchOnVerdict::On;
    }
    // Lit from the first flip, which lands face up and so is the first moment
    // there is anyone to read it. A wake in a bag never gets this far, and
    // stays dark. The panel then stays up until the cube sleeps or is switched
    // on, face down between flips included.
    if (listener.flipsToGo() < SWITCH_ON_FLIPS) Display::showFlipsToGo(listener.flipsToGo());

    delay(20);
  }
}
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
void loop() {
  // Passes are paced to start LOOP_PASS_MS apart, the wait filling whatever
  // the last pass left of that rather than being added to it. A fixed delay
  // was free while a pass was nothing but the delay, and once drawing a
  // leaning face took 37 ms it made every frame 20 ms later than it had to be.
  // Never less than a millisecond, so a run of long passes still hands the
  // core back to the scheduler between them.
  //
  // How far apart is decided at the end of the pass before, by Util::loopPassMs:
  // fast while anything needs it, slower while the cube just sits dimmed.
  //
  // An idle wait is light-slept rather than spun through, unless the radio is
  // on the air: see Nap and BLE::onAir().
  static uint32_t passStart = 0;
  static uint32_t passMs = LOOP_PASS_MS;
  static bool idle = false;
  const uint32_t spent = millis() - passStart;
  const uint32_t wait = spent < passMs ? passMs - spent : 1;
  // What a soak run reads: how much of each minute went to naps, and whether
  // the heap is holding steady through the radio's bring-ups and teardowns.
  static unsigned long lastSoak = 0;
  static uint32_t napMs = 0, naps = 0;
  if (millis() - lastSoak >= 60000UL) {
    Serial.printf("[trace] SOAK t=%lu naps=%u napMs=%u heap=%u largest=%u\n", millis(),
                  (unsigned)naps, (unsigned)napMs, (unsigned)ESP.getFreeHeap(),
                  (unsigned)ESP.getMaxAllocHeap());
    lastSoak = millis();
    naps = napMs = 0;
  }
  if (idle && wait >= NAP_MIN_MS && !BLE::onAir()) {
    Display::finishDrawing();
    Nap::sleepFor(wait);
    naps++;
    napMs += wait;
  } else {
    delay(wait);
  }
  passStart = millis();

  Display::render();

  float ax, ay, az;
  const bool haveReading = QMI::getAccelerometer(ax, ay, az);
  // Followed throughout, drawn only while there is a face to turn: a paused
  // frame stays square on the face it was parked from.
  const bool turned = senseTilt(haveReading, ax, ay, az);
  if (turned && !paused) Display::setAngle(tilt.angle());
  // Moving is anything but resting still on the face it is believed to be on:
  // being handled, on its way to another face, or a face still easing round.
  if (turned || (haveReading && (!Util::isGravityOnly(ax, ay, az) ||
                                 Util::calcOrientation(ax, ay, az) !=
                                     Util::getDebouncedOriState()))) {
    lastMoved = millis();
  }

  if (haveReading) {
    if (Util::updateOriDebounce(ax, ay, az, millis())) {
      Orientation ori = Util::getDebouncedOriState();
      lastFaceChange = millis();

      Serial.printf("[trace] FACE t=%lu ori=%d\n", millis(), (int)ori);
      if (Util::isRestingFace(ori)) {
        // Both resting faces park the timer, stored against the face it was
        // running on and picked up again only by that face. A flow stint is
        // parked rather than ended -- standing the cube back on its face carries
        // on counting up. The two faces differ only in the screen.
        const Util::RestPlan plan =
            Util::restOnFace(RtcState::data(), ori, lastTimerFace, remSeconds, selSeconds,
                             countingUp());
        if (plan.lit && RtcState::hasPause(RtcState::data())) {
          // Paused, and staying awake for it, so that leaving the pause is a
          // face change rather than a wake.
          Haptic::play(Haptic::Pattern::FaceChange);
          holdPause();
          return;
        }
        if (plan.lit) {
          if (lastTimerFace != Orientation::UNDEFINED) Display::rotateScreen(lastTimerFace);
          Display::showPaused();
        }
        Util::deepSleep(plan.mode, true);
      }

      // Replaces whatever was playing, which is what silences an alarm: a
      // finished timer buzzes until the cube is turned to something else.
      Haptic::play(Haptic::Pattern::FaceChange);
      applyFace(ori);
    }
  }

  {
    static unsigned long lastTrace = 0;
    // Not while idle, where it would be most of what a pass does and the UART
    // would have to be flushed out ahead of every nap.
    if (!idle && millis() - lastTrace >= 200) {
      lastTrace = millis();
      Serial.printf("[trace] awake t=%lu ori=%d ok=%d dec=%d a=%.3f,%.3f,%.3f\n", millis(),
                    (int)Util::calcOrientation(ax, ay, az), (int)Util::isGravityOnly(ax, ay, az),
                    (int)Util::isDecisive(ax, ay, az), ax, ay, az);
    }
  }

  // A tap only ever buys brightness, so it is read here and left to the
  // backlight policy below. Nothing else on the cube changes because it was
  // touched -- the faces are what choose the timer. Single or double, either
  // counts: what was asked for is a tap. Narrowing this to Tap::Double is the
  // whole change if single taps turn out to fire at things that were not taps.
  //
  // Read every pass so the sensor's latch is cleared, but not believed while
  // the motor is running: the tap detector cannot tell a finger from the cube
  // shaking itself.
  if (QMI::takeTap() != QMI::Tap::None && !Haptic::disturbing()) lastTap = millis();

  if (paused) {
    // Nothing counts and nothing alarms. Long enough forgotten, the cube goes
    // to sleep holding the frame, as a pause always used to from the start.
    if (millis() - pausedAt >= PAUSE_AWAKE_MS) {
      Display::showPaused();
      Util::deepSleep(Util::SleepMode::Paused, false);
    }
  } else if (countingUp() && millis() - lastTick >= 1000) {
    remSeconds++;
    // Stepped on from the tick it was due, not from the pass that noticed it,
    // or every second would run long by however late that pass was.
    lastTick += 1000;
    // Every lap of the arc is a pomodoro, scored as the lap closes rather than
    // when the stint ends: two hours of flow is four pomodoros, and the count
    // reaches Home Assistant while the stint is still running.
    if (Util::completesFlowLap(remSeconds)) RtcState::data().pomodoroCount++;
    Display::updateTimer(timerView());
  }

  if (!paused && !countingUp() && remSeconds > 0 && millis() - lastTick >= 1000) {
    remSeconds--;
    // Keep the balance in step as the break is spent, so whatever interrupts it
    // -- another face, a pause, a flat battery -- leaves the rest still banked.
    if (spendingFlowBank) RtcState::setFlowBank(RtcState::data(), remSeconds);
    Display::updateTimer(timerView());
    lastTick += 1000;
    if (remSeconds == 0) {
      startedAlarm = millis();
      // Only work timers count as pomodoros; breaks do not. Flow stints are
      // counted a lap at a time, as they run.
      if (timerKind == TimerKind::Work) RtcState::data().pomodoroCount++;
    }
  }

  if (!paused && !countingUp() && remSeconds == 0) {
    // Asked for on every pass and started once: a repeating pattern that is
    // already playing is left to carry on. Not before a face is established,
    // where the timer reads as finished only because there is not one yet, and
    // a motor running in the hand would keep the cube from settling on a face.
    if (lastTimerFace != Orientation::UNDEFINED) Haptic::play(Haptic::Pattern::Alarm);
    Display::cycleTimerFinish();
    // Unannounced: thirty seconds of alarm has said everything a parting buzz
    // could.
    if (millis() - startedAlarm >= 1000 * 30) Util::deepSleep(Util::SleepMode::Off, false);
  }

  Haptic::cycle();

  // Last, so it sees the tick this pass produced rather than the one before it.
  const int backlight = Util::backlightPercent(
      {millis() - lastFaceChange, remSeconds, countingUp(), sinceTap(), paused,
       millis() - lastTick});
  Display::setBacklight(backlight);
  // Takes effect from the next pass's render, which is the first one it could.
  static uint32_t cpuMhz = CPU_MHZ_IDLE;
  if (Util::cpuMhz(backlight) != cpuMhz) {
    cpuMhz = Util::cpuMhz(backlight);
    setCpuFrequencyMhz(cpuMhz);
    Serial.printf("[trace] CPU t=%lu mhz=%u\n", millis(), (unsigned)getCpuFrequencyMhz());
  }

  Battery::cycleBatteryUpdate();

  // Offered unconditionally, after the battery so the voltage is this pass's:
  // the sequencer behind this only reaches for the radio when the payload has
  // actually changed, which is a cheaper thing to get right than remembering to
  // publish at each of the places state moves.
  //
  // Not before a face is established, though. Between waking and the debounce
  // settling there is no timer at all, and the fields for that read as a flow
  // stint at zero seconds -- a state the cube is not in, and one it would
  // otherwise broadcast for the first 300 ms of every wake.
  if (lastTimerFace != Orientation::UNDEFINED) BLE::publish(bthomeState());
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

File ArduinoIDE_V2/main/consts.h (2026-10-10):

#pragma once
#include <stdint.h>

#include "ui_colors.h"

#define BAT_ADC_PIN 1
#define TFT_BL_PIN 2
#define IMU_INT_PIN GPIO_NUM_4
#define I2C_SDA_PIN 6
#define I2C_SCL_PIN 7
// The vibration motor's driver input: high runs the motor. One of the six GPIOs
// the board brings out on its SH1.0 connector (15, 16, 17, 18, 21 and 33). This
// one because it is in the RTC domain, so its level can be held through deep
// sleep, and is not a strapping pin, so a motor hanging off it cannot change
// how the board boots.
#define HAPTIC_PIN 15

#define ORI_DEBOUNCE_DELAY 300

// How many accelerometer reads in a row have to fail before the I2C bus and
// the QMI8658 are recovered and set up again (see QMI::getAccelerometer), and
// how long to leave between attempts while it stays silent. 25 is half a second
// of 20 ms passes: no glitch lasts that long, and no face change is missed for it.
constexpr unsigned QMI_RECOVER_AFTER_FAILURES = 25;
constexpr unsigned long QMI_RECOVER_INTERVAL_MS = 5000;

// A reading only says which way is down when it is gravity and very little
// else. Outside this band the cube is being accelerated -- carried, tapped, set
// down hard -- or the QMI8658 is still coming up after being configured, which
// it does by emitting a few samples of nonsense. Measured on the board: at rest
// the magnitude sits at 1.01 g and barely moves; the rejected samples in a
// fifteen-minute trace ran from 0.00 to 2.64 g, so nothing near the edges of
// this band is a real attitude.
constexpr float ORI_GRAVITY_MIN_G = 0.85f;
constexpr float ORI_GRAVITY_MAX_G = 1.15f;

// How far the dominant axis has to lead the runner-up before a reading is
// allowed to move the cube onto a *new* face. An attitude poised between two
// faces goes on confirming the face the cube is already believed to be on, and
// is never enough to move it, so a cube resting near the halfway point does not
// alternate between the two.
constexpr float ORI_DOMINANCE_MARGIN_G = 0.10f;

// The face is drawn upright against gravity at whatever angle the cube is held,
// rather than at the nearest quarter turn. That needs some of gravity to lie in
// the plane of the screen: below this much, the cube is close enough to flat
// that the angle is mostly noise, and the face stays where it last was.
constexpr float TILT_MIN_INPLANE_G = 0.30f;

// Within TILT_SNAP_CAPTURE_DEG of a quarter turn the face is drawn at exactly
// that quarter turn, and stays there until the cube is more than
// TILT_SNAP_RELEASE_DEG off it. A cube stood on a face is never quite square to
// gravity -- the desk is not level and neither is the print -- and the gap
// between the two figures is what stops one resting near the edge of the first
// from flickering in and out of it. Measured on the board, a reading at rest
// wanders by about a degree and a half, which both are well clear of.
constexpr float TILT_SNAP_CAPTURE_DEG = 8.0f;
constexpr float TILT_SNAP_RELEASE_DEG = 12.0f;

// Two time constants, in milliseconds. The first smooths the readings, which
// is what keeps a hand's unsteadiness out of the angle. The second eases the
// face towards wherever the readings point, which is what turns the jumps --
// snapping onto a quarter turn, letting go of one -- into movement. Neither has
// been tuned against a cube in the hand.
constexpr int TILT_SENSE_SMOOTHING_MS = 50;
constexpr int TILT_EASE_MS = 70;

// How far the angle has to move before the face is drawn again. Every redraw
// at an angle is the whole panel sent over SPI, so movement too small to see
// is not worth one.
constexpr float TILT_REDRAW_STEP_DEG = 1.0f;

// How much movement wakes a sleeping cube, in milli-g, as the QMI8658's
// wake-on-motion detector counts it. The vendor default of 200 mg wanted a
// deliberate knock: picking the cube up and standing it on a face often failed
// to reach it, so the cube sat there still showing what it was showing when it
// was put down, and had to be tapped awake.
//
// Set from the noise floor measured on the board rather than picked: at rest
// the sample-to-sample movement averages 5 mg and its 99th percentile is 24 mg,
// so this is comfortably clear of a cube sitting still on a desk while being
// three times more sensitive than the default. A spurious wake is cheap now in
// a way it was not before -- the settling below sends a cube that has not
// actually moved back to sleep in about a third of a second.
constexpr uint8_t WAKE_ON_MOTION_THRESHOLD_MG = 64;
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

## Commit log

2026-09-22 Retime the cube for pomodoro intervals
    25 minutes on the default face, then 5, 50 and 10 going clockwise, in
    place of the inherited coffee brew times.
    Replaces the timers[4] array with named constants. The array was indexed
    in the order 3, 0, 1, 2, so its own order meant nothing and the
    face-to-duration mapping could only be read by cross-referencing two
    files. Keeping it would have meant writing {300, 3000, 600, 1500}.
    The fallback for SLEEP and UNDEFINED is now the work timer rather than
    the first array element. It has to stay non-zero: Display::updateTimer()
    divides by selSeconds when computing arc progress.
    Which rotation direction DEG_90 represents is an assumption. The enum
    maps ont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
    [consts.h, util.cpp]
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2026-09-22 Redesign the screen around the timer, not the battery
    Two changes to what the panel shows.
    The arc now starts full and drains, shading green through amber to red
    as the time runs out, rather than filling from empty in a fixed blue.
    Stops are 100% green, 50% amber, 25% red, interpolated between and flat
    below the last one. The knob follows the ring, having previously been
    stuck on the theme's blue.
    The battery bar and percentage label are gone. Above 3.6V nothing is
    shown at all; below it, an empty battery outline in red with the
    measured pack voltage printed inside, so the 200k/100k divider and the
    ESP32 ADC can be checked against a multimeter once the hardware exists.
    The threshold is in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
    [consts.h, display.cpp]
2026-09-22 Add a desktop simulator and host tests
    There is no hardware yet, so this builds the firmware for a Linux
    desktop and draws LVGL into an SDL window instead of a GC9A01 over SPI.
    The firmware is not forked for it. main.ino, display.cpp, util.cpp,
    indicators.cpp, battery.cpp and beeper.cpp compile exactly as they ship,
    against fake Arduino.h, TFT_eSPI, Wire and driver/rtc_io headers under
    sim/shim/. A simulator that reimplemented the countdown would drift from
    the firmware and stop being evidence of anything. The one source that
    cannot be host-compiled is qmi.cpp, which needs the vendor QMI8658
    driver; sim/src/sim_qmi.cpp synthesises accelerometer vectors chosen so
    Util::calcOrientation() maps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
    [Arduino.cpp, main.cpp]
2026-09-22 Distinguish face-up from face-down
    calcOrientation() collapsed both resting faces into a single SLEEP state
    via `az < -0.8 || az > 0.8`, because a coffee timer never needed to tell
    them apart. A pomodoro timer does: face-down is going to mean "off" and
    face-up "paused".
    Behaviour is unchanged -- both faces still deep-sleep, through a new
    Util::isRestingFace() rather than an equality test. This only makes the
    distinction available.
    Which sign of az is which is a guess. It assumes the QMI8658's +Z leaves
    the front of the cube, so an accelerometer at rest reads +1g when the
    screen faces the ceiling. If it turns out swapped on real hardware, the
    two lines in calcOrientation() exchange and noth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
    [consts.h, main.ino, test_util.cpp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]
2026-09-22 Keep state across deep sleep in RTC memory
    The ESP32 keeps a small block of RAM powered through deep sleep and
    loses it on a power cycle. That is the right home for a paused timer and
    for the completed-pomodoro count, neither of which should survive a flat
    battery but both of which must survive the cube being set down.
    The catch is that a cold boot leaves arbitrary bits in that block, and
    nothing about reading "847 seconds remaining" says whether the last run
    wrote it or whether it is noise that happens to look plausible. So the
    block carries a magic word, and anything that does not match it is
    discarded and re-initialised. The constant encodes a version, so a
    firmware whose struct layout c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
    [main.cpp, main.ino]
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2026-09-22 Encode the cube's state as a BTHome v2 advertisement
    Home Assistant discovers BTHome natively, so advertising in that format
    means no custom component and no MQTT. The payload carries a packet id,
    pack voltage, a connectivity flag, whether the timer is running, the
    pomodoro count, and two durations -- 28 of the 31 bytes a legacy
    advertisement allows.
    Assembling the bytes is the part that is easy to get wrong and easy to
    test, so it lives on its own with no reference to a radio. Nothing
    transmits it yet; the NimBLE plumbing needs the board. The simulator
    prints what would go out when you press `a`.
    Tested against exact bytes rather than round-tripping through the
    encoder's own logic, since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
    [main.cpp, test_bthome.cpp]
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2026-09-23 Model the enclosure as a parametric 55 mm cube
    The original this project forks its firmware from ships STLs for a
    55 x 55 x 62 mm box, which is not a cube and carries its battery bay,
    beeper hole, numerals and M2 fixings baked into the mesh. This is a
    parametric replacement for the shell alone, built with build123d and
    exported as STEP so it can be opened and fitted out in Fusion 360.
    Dimensions were measured off the original's meshes rather than guessed:
    3.00 mm walls, a 6.00 mm vertical corner radius, a 0.50 mm bottom edge
    chamfer, and a 37.81 mm LCD aperture, which leaves a 0.35 mm lip for
    the Waveshare module's 38.51 mm face while masking none of its 33.40 mm
    active area.
    Three parts s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
    [back-plate-plates-as-faces.step, back-plate-plates-inset.step, band-plates-as-faces.step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]
2026-09-23 Hold the board, and drop the inset-plate variant
    Settles the open seam question in favour of plates-as-faces and removes
    the other variant, then adds what the shell was missing: something that
    positively attaches the Waveshare board.
    The board has no mounting holes — its only through-holes are 0.50 and
    0.76 mm vias — so it cannot be screwed down. The original clamps it, and
    so does this. Two mechanisms do the work, both measured off the original
    rather than invented.
    The display opening turns out not to be a bore at all. It is a 28.4
    degree cone, 38.94 mm at the outer face narrowing to 35.70 mm at the
    inner one. The module is 38.51 mm across, so it can neither pass through
    nor sit prou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
    [back-plate-plates-inset.step, back-plate.step, band-plates-inset.step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]
2026-09-23 Cut the USB-C opening the shell was missing
    There was no hole for the socket. The original has one, and finding it
    took two tries: an initial ray scan reported all four walls solid,
    because it asked whether a ray hit anything at all, and a ray through a
    hole still hits the far wall. Measuring the first hit's distance instead
    shows a 12.00 x 6.25 mm cutout in one wall, centred, running 6.00 to
    12.25 mm in from the display face.
    That is now cut into the band, positioned off the display's outer face
    rather than off the band's own base, since the board hangs from that face
    and the opening has to stay lined up with the socket when other
    dimensions move. The socket cannot leave through the back p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
    [back-plate.step, band.step, clamp-bar.step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]
2026-09-24 Derive the enclosure from the board's own STEP
    The board figures the model carried were partly wrong, and three of the
    enclosure's numbers were inconsistent with each other as a result. Measured
    Waveshare's published STEP with build123d and made every board dimension a
    named parameter in cad/board.py, so the seat depth, the clamp height and the
    USB-C opening now derive from the board rather than being copied from the
    original.
    What the STEP says, against what the model assumed:
    - The PCB is Ø37.54, not Ø39.53. The larger figure is the board's span
    including its USB-C tab, so the bars overlap the rim by 2.27 mm, not 3.27.
    - The outline is a circle with a trapezoidal tab, not a chord fla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
    [back-plate.step, band.step, clamp-bar.step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]
2026-09-24 Replace the 50/10 pair with flow mode
    The third face now counts up for as long as the cube stands on it, and the
    fourth counts down a fifth of what it counted. Fifty minutes of work still buys
    ten of break, which is what the fixed pair did; anything else now works too.
    A stint's time is banked when it ends and only the break face spends it, which
    is what makes the handoff survive a pause: parking a stint face-up stores both
    a resumable pause and the banked time, and whichever face the cube lands on
    next claims one of them. Both work faces count towards the pomodoro total now,
    so the count keys off a TimerKind rather than off the 25-minute length.
    The panel inverts to black on white while c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
    [consts.h, display.cpp, main.cpp]
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2026-09-24 Drop the fixed fallback for an empty flow bank
    Turning to the flow break face with nothing banked gave ten minutes. That was
    the last value in flow mode conjured rather than earned, and it needed a rule
    of its own to stop it being credited back -- the break that does not write to
    the bank. It now counts down from nothing: 00:00, the finish pattern, and the
    usual half minute before sleeping.
    TIMER_LONG_BREAK_SECONDS goes, and TimerSpec::spendsBank loses its condition --
    every flow break comes from the bank now, so the break face always writes back
    and the fixed faces never do.
    Two things had to give way for a zero-length countdown to be a legal state.
    A face change landing on one now dates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
    [consts.h, main.ino, test_util.cpp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]
2026-09-24 Invert both flow faces, and show the bank while working
    The break face was still wearing the fixed faces' dark palette, which put the
    two halves of flow mode in different liveries even though the break is spending
    exactly what the work face banked. Both faces now invert, and TimerSpec::flow
    says which faces those are rather than the display inferring it from whether
    the timer happens to be counting up.
    The flow work face also carries the bank above the counter in small type. It
    shows what the bank would be worth if the stint ended now -- the balance plus a
    fifth of the seconds counted so far -- rather than the last committed figure,
    which would sit unchanged for the whole stint. The questio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
    [display.cpp, main.cpp, main.ino]
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2026-09-24 Swap the ramp onto the background while dim
    A thin arc at 20% backlight is not readable across a desk; a field of
    colour is. Dim mode now makes the arc colour the whole face and draws
    everything over it in what used to be the background -- black over the
    countdown's brighter ramp, white over flow's darker one. The face shifts
    green to amber to red as the timer runs out, and the shrinking arc still
    gives the fraction. Bright mode is unchanged, and is one glance away
    whenever the exact reading matters.
    The swap is literal, which is what makes it cheap: the foreground takes
    SCREEN_BG_COLOR or FLOW_BG_COLOR, so no new colours are needed and the
    contrast is right by construction. Costs nothing i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
    [display.cpp, main.cpp]
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2026-09-24 Fix which way is up, and stop the paused frame going dark
    The accelerometer polarity was a guess and it was backwards: +Z points
    into the back of the cube, so a cube resting screen-up reads -1g. Setting
    it down to be read was turning it off.
    The paused frame blanked a few seconds after set-down because deep sleep
    returns TFT_RST to high impedance, where it drifts low and resets the
    panel. Hold it high the way the backlight already is.
    [display.cpp, test_util.cpp, util.cpp]
2026-09-24 Put the BTHome advertisement on the air
    The encoder has been written and tested since the start, and the simulator
    would print a payload on demand, but nothing ever transmitted one -- so Home
    Assistant's BTHome flow, which only offers devices its Bluetooth integration
    has actually seen, had nothing to find.
    ble.cpp is the missing half. A non-connectable advertisement with no scan
    response and no GATT server: a BTHome device is a broadcast, and that is the
    shape that costs least. The payload goes out whole rather than assembled from
    NimBLE's field setters, because bthome.cpp already emits exactly the bytes that
    have to appear.
    BTHome::Sequencer decides when there is anything to say, so the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
    [main.cpp, main.ino]
2026-09-24 Stop the cube parking itself on its way to a working face, and let it be tapped
    Returning from paused sometimes left the paused frame up instead of the
    timer. Two separate causes, either enough on its own:
    The orientation debounce reset its clock only on samples agreeing with
    the face already accepted, so once the cube left that face nothing reset
    it again and whichever reading landed 300ms later was taken as a
    decision. Picking a cube up off its face-up rest reads face up on the
    way, which parked it again on a face it was no longer on -- where
    nothing was left to wake it. It now times the candidate: any change of
    reading restarts the clock.
    And the wake path decided from one accelerometer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
    [consts.h, display.cpp, main.cpp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]
2026-09-24 Name the face by the dominant axis, not by a threshold
    Instrumenting the board found what the debounce fix did not: 38.8% of
    every accelerometer sample in a fifteen-minute trace fell in a dead zone
    that calcOrientation() answered with its final `return DEG_0` -- a timer
    face reported because nothing matched, not because the cube was on it.
    Testing each axis against a fixed +-0.8 requires gravity within 37
    degrees of an axis, and the board at rest sits 37.3 degrees off Y with a
    Y component of -0.7965, straddling the threshold it is judged by.
    The consequences, both captured on the device. Sitting perfectly still,
    the cube alternated between DEG_90 and the DEG_0 fall-through, starting
    a fresh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
    [consts.h, main.ino, test_util.cpp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]
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2026-09-24 Stop the paused frame being reset off the panel, and wake on less
    Two regressions from the sleep/wake work, both found on the board.
    holdPausedFrame() released the pad holds before re-driving them. When
    they were already on -- which is every wake that finds the cube still
    face up -- they were already holding exactly the levels it was about to
    ask for, so the release bought nothing and handed the panel's reset line
    back to an output register that waking from deep sleep clears to zero.
    The pad presented a LOW until the register was written again, which the
    GC9A01 took as a reset: frame memory cleared, controller back in
    sleep-in, and the backlight still held up over a blank panel a couple of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
    [consts.h, display.cpp, qmi.cpp]
2026-09-25 Keep the farewell advertisement on the air through the whole shutdown
    The farewell -- the one advertisement that drops connectivity and running,
    and the only one that can describe a pause -- went out at 100 ms for a fixed
    400 ms and then the radio was shut down, before the panel was put away, the
    second's pause, and the shutdown beeps. Four copies, and a receiver scanning
    at a low duty cycle (an ESPHome proxy listens 30 ms in every 320) could miss
    all of them; Home Assistant then held a stale running=true.
    BLE::farewell() now only puts the advertisement on the air and returns. A new
    BLE::shutdown(), called last in Util::deepSleep() immediately before
    esp_deep_sleep_start(), shuts the contro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
    [main.cpp, test_sleep_sequence.cpp, util.cpp]
2026-09-27 Replace the beeper with a vibration motor
    The cube is getting a vibration motor and no sounder, so the beeper goes
    and the motor takes its pin: GPIO15, one of the six the board brings out
    on its SH1.0 connector, in the RTC domain so it can be held low through
    deep sleep, and not a strapping pin. Driving it high runs the motor.
    It buzzes twice on waking onto a timer face, once when the cube is set on
    a different face, and on and off for as long as a finished timer goes
    unanswered. Turning the cube to another face is what silences that.
    The motor shakes the accelerometer that everything else depends on, so:
    - A wake that finds the cube still resting goes back to sleep in silence.
    A buzz t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
    [Arduino.cpp, consts.h, display.cpp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]
2026-09-27 Draw the face upright against gravity at whatever angle the cube is held
    The face used to be drawn at the nearest quarter turn and swapped to the
    next one in a single frame. It now follows the angle of gravity in the
    plane of the screen on every pass, so turning the cube turns the picture
    with it, and a cube held at 45 degrees shows a face at 45 degrees.
    Which timer runs is not affected. That is still the debounced face; this
    is only the angle the picture is drawn at.
    - Tilt::Tracker smooths the readings and eases the drawn angle towards
    where they point, the short way round, on the clock rather than per
    pass -- a slow redraw gives a turn in fewer frames, not a longer turn.
    - Within 8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
    [consts.h, display.cpp, main.cpp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]
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2026-09-28 Reboot on a hang instead of freezing
    Nothing watched the task that runs setup() and loop(): arduino-esp32 only
    puts it under the task watchdog when enableLoopWDT() is called, and the
    firmware never called it. A pass of loop() that never came back -- an I2C
    read that hangs, a wait that never ends -- left the cube frozen on its last
    frame until the battery ran out or someone pressed reset.
    Arm it at the top of setup() so a pass that takes longer than the 5 s
    watchdog timeout panics and reboots. The longest deliberate block, going to
    sleep, is a little over two seconds. The wake settle can use up to three of
    setup()'s five, so setup() feeds the watchdog once the settle is done. Log
    the reset r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
    [Arduino.cpp, main.ino]
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2026-09-28 Listen for switch-on from the wake, and ask for it on screen
    On the board the gesture mostly failed, for two reasons. Lifting a face-down
    cube woke it while it was still face down; it settled, went back to sleep,
    and finished doing so while it was being turned over, so the double tap was
    spent waking it. And a cube turned face down while it slept face up was only
    asleep, never switched off, so there was nothing to switch on.
    A switched-off cube now listens from the moment it wakes, for up to five
    seconds and five more once it lies face up, and gives up after a second and a
    half still on any other face. While it is face up and listening it shows
    "Double-tap to start". Any wake that settles f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
    [consts.h, display.cpp, main.cpp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]
2026-09-28 Lower the tap threshold and say what to do after switching on
    The tap engine's peak threshold was the datasheet's example of 0.8 g^2,
    about 0.9 g. On a cube lying on a hard desk that let through two taps out of
    a dozen double taps, as singles, so the cube could not be switched back on.
    At 0.25 g^2 double taps come through on the board.
    A cube switched on with no paused timer used to go dark straight away, which
    looked like the switch-on had failed. It now shows "Stand on a side to
    start" for three seconds, and starts a timer at once if it is stood on a
    face in the meantime. The message screen behind the double-tap prompt is now
    a general Display::showMessage().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
    [consts.h, display.cpp, main.ino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]
2026-09-28 Answer a switch-on with "Let's go", black on white
    Inverted from the "Double-tap to start" prompt, so the change from asking to
    answered is plain at a glance.
    [consts.h, display.cpp, main.ino]
2026-09-28 Lower the tap threshold again, to 0.15 g^2
    0.25 g^2 still missed taps on the glass now and then.
    [qmi.cpp]
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2026-09-29 Wipe the panel before lighting it
    The GC9A01 keeps its frame memory through sleep-in and reset, so the
    last frame drawn before the cube slept showed for a moment under the
    backlight on the way up, most visibly ahead of "Shake to start".
    [display.cpp]
2026-09-29 Light the panel only once a frame is on it, and ask for a harder shake
    Wiping the glass before the backlight shortened the glimpse of the last
    frame on the board without ending it, so the backlight now stays off
    until the first frame has been drawn.
    A shake has to be half a g off gravity rather than anything outside the
    gravity band, which handling the cube was enough to reach.
    [consts.h, display.cpp, test_util.cpp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]
2026-09-29 Redraw only what changed on each tick
    LVGL redraws an object whenever a style is set on it or it is shown,
    whether or not anything changed. updateTimer() repainted every colour
    once a second, starting with the screen's background, so every tick
    pushed the whole 240x240 frame over SPI in twenty-line bands -- slowly
    enough to see it arrive. The colour, opacity and visibility setters now
    skip values that are already in place, as does the arc's rotation.
    In the simulator a steady countdown goes from 57,600 pixels a second
    to about 17,000. The arc's own colour ramp still redraws the full ring
    every couple of seconds; that is a real change, and is what a faster
    bus is for.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
    [display.cpp]
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2026-09-29 Tell LVGL how much time has really passed
    loop() advanced LVGL's clock by a fixed 20 ms a pass, which stopped
    being true once a pass included drawing a leaning face. LVGL then
    under-counted time, found its 30 ms refresh period not yet up, and
    skipped passes. Display::render() now feeds it the real elapsed
    millis() before running it, for loop() and pumpLvgl() alike.
    On the board, with the face held at a 15 degree lean and redrawn every
    pass, the frame rate went from 7.5 fps to 9.
    [display.cpp, main.ino]
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2026-09-29 Pace loop passes rather than delaying a fixed 20 ms after each
    loop() drew, then waited 20 ms, so every frame arrived 20 ms after it
    was ready. Passes now start at least LOOP_PASS_MS apart, the wait
    filling whatever the last pass left of that, with a millisecond's floor
    so a run of long passes still yields to the scheduler.
    A pass that does little still takes 20 ms, so shake detection's
    readings still come at least that far apart; everything else in the
    loop is timed by millis(). On the board, with the face held at a 15
    degree lean and redrawn every pass at 240 MHz, 17 fps became 25.
    [consts.h, main.ino]
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2026-09-30 Let the simulator run its clock faster than real time
    SIM_TIME_SCALE speeds up millis(), micros() and delay(), and the scripted
    keys and screenshots are now timed on millis() rather than SDL's clock,
    so their times stay in simulated milliseconds. A flow stint past its
    first hour, which the README describes but no screenshot could show
    without waiting the hour out, is six seconds away at 600.
    A ctest runs half an hour of flow at 600x and fails if it takes more
    than 20 seconds.
    [Arduino.cpp]
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2026-09-30 Replace the code-built enclosure with the Fusion 360 design
    The build123d model described a 55 mm cube the design has long since moved
    past; the enclosure is now the Fusion document "Pomodoro Box", a 44.9 mm cube
    in four parts. cad/ now holds its .f3d, an assembly STEP and print-oriented
    STLs, and the old model lives on in history.
    [back-plate.step, band.step, clamp-bar.step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]
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
